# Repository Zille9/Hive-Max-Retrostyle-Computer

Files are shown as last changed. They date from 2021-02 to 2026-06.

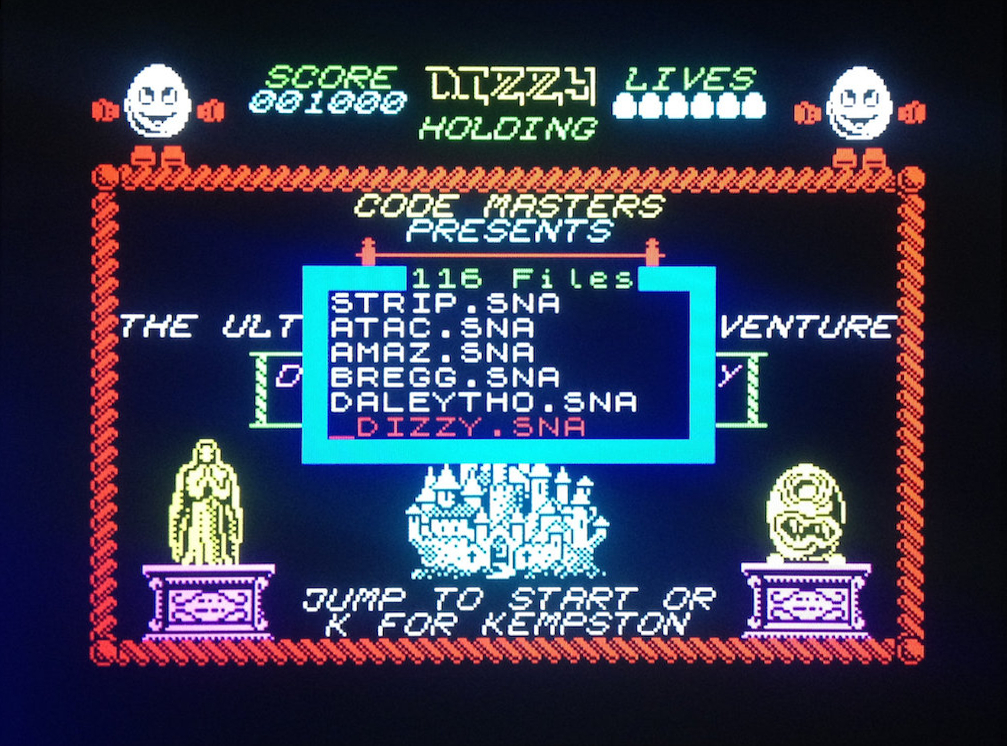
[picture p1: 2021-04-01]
Pictures/spectrum.JPG

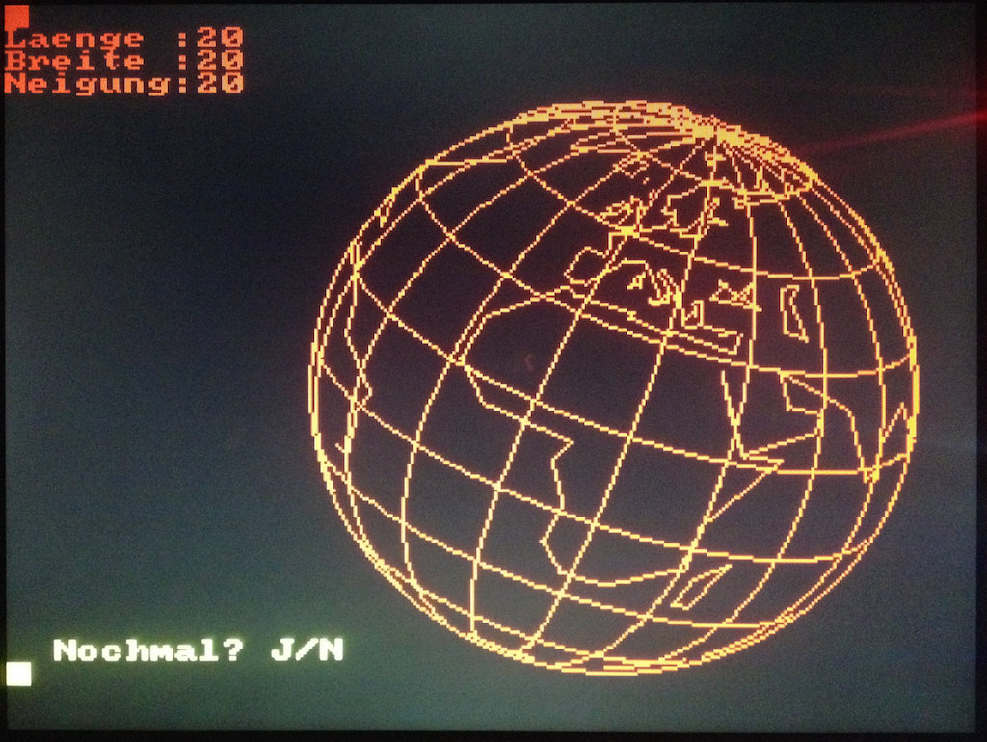
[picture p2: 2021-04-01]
Pictures/IMG_1200.JPG

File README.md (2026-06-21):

# Hive-Max-Retrostyle-Computer
umfangreich erweiterter Hive-Retrostyle-Computer

Folgende Änderungen wurden durchgeführt:
- 2xJoystick Ports (wie Mini-Joystickkarte)
- Bellatrix-Ram-Erweiterung integriert (für Emulatoren)
- Umschaltung Soundquelle von Administra nach Bellatrix (für Emulatoren)
- zusätzlicher Latchbaustein für die Aktivierung/Deaktivierung zusätzlicher Funktionen
- Portsperren am Bellatrix VGA-Ausgang, um die Ports für eigene Erweiterungen zu nutzen (andere Grafikhardware, CP/M-Emulation usw.)
- Möglichkeit der Anbindung des Micromite an den Hive
- Expansionsport als C64 Modulport ausgebildet für Hardware-Steckmodule
- automatische EEPROM-Umschaltung durch die Steckmodule über Adressumschaltung
- Latch-Diagnoseanschluss für den Zusatzlatch zur Funktionskontrolle

Für weitere Informationen siehe auch https://hive-project.de

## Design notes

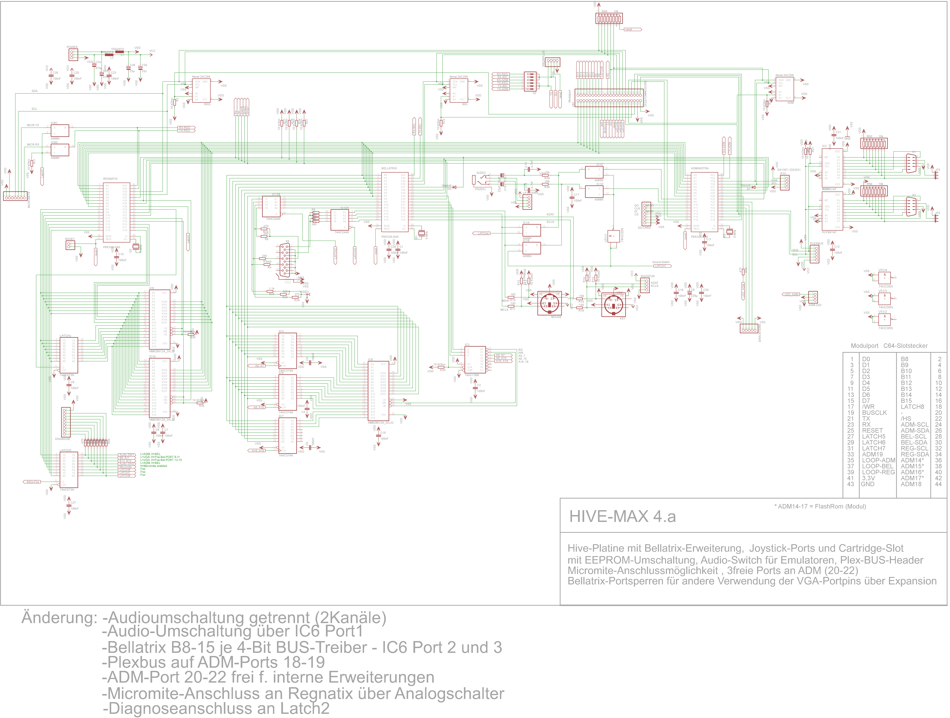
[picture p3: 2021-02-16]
Hive_Max_4a-Schematic.png

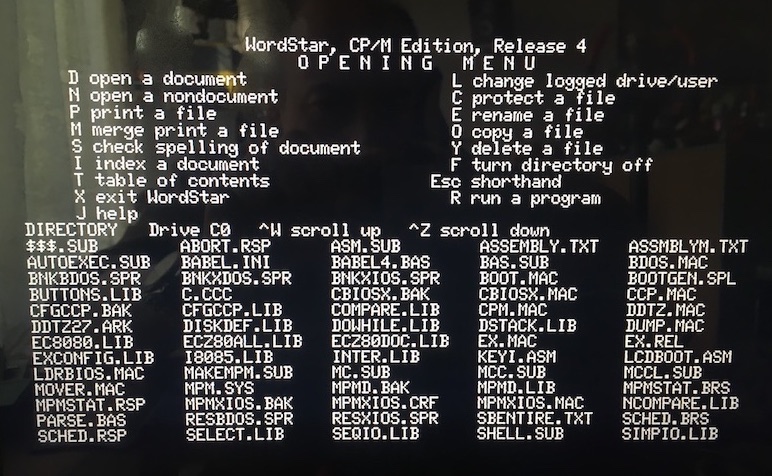
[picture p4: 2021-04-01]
Pictures/CPM-Hive.JPG

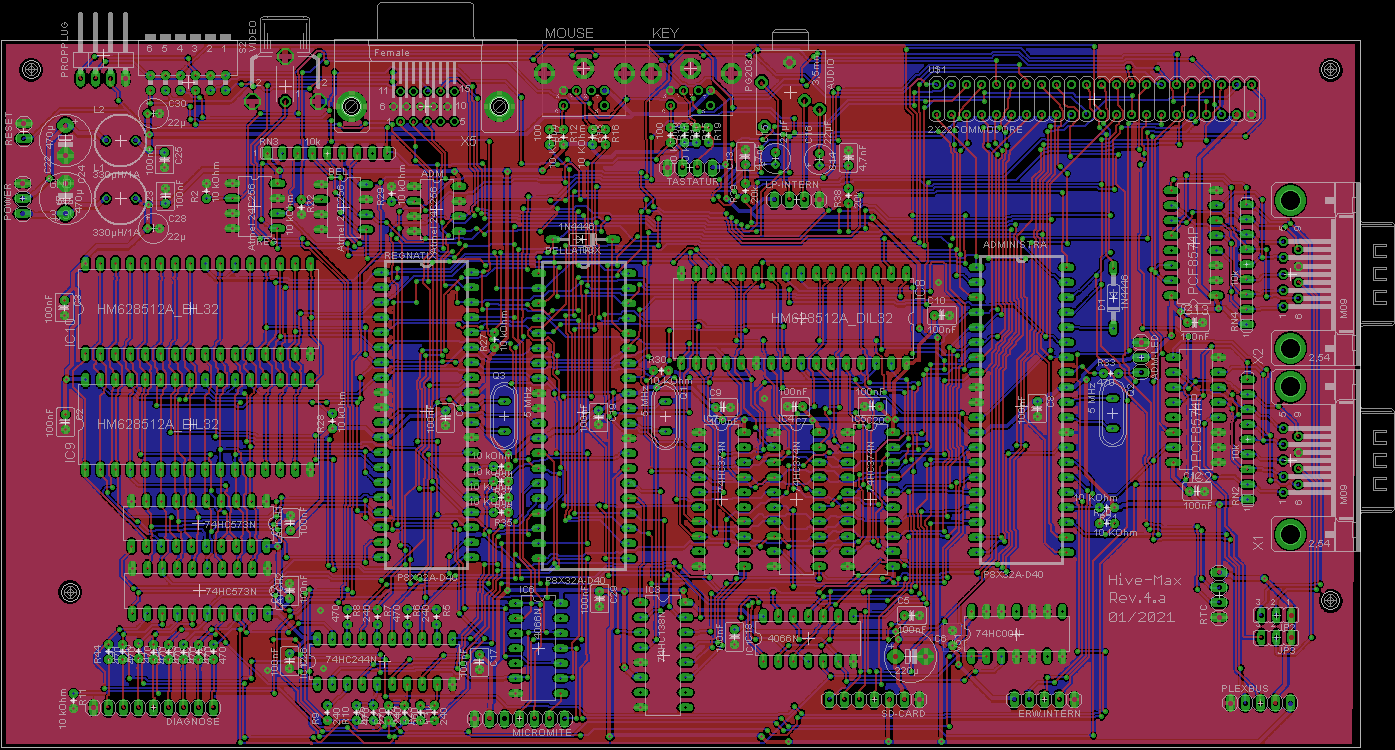
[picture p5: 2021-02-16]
Hive_Max_4a-Board.png

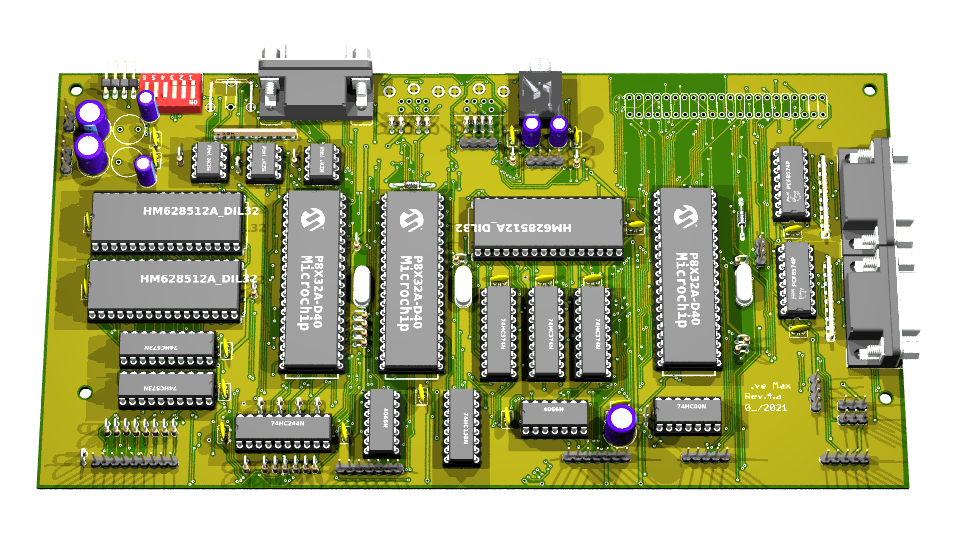
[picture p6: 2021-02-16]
3D-Ansicht.png

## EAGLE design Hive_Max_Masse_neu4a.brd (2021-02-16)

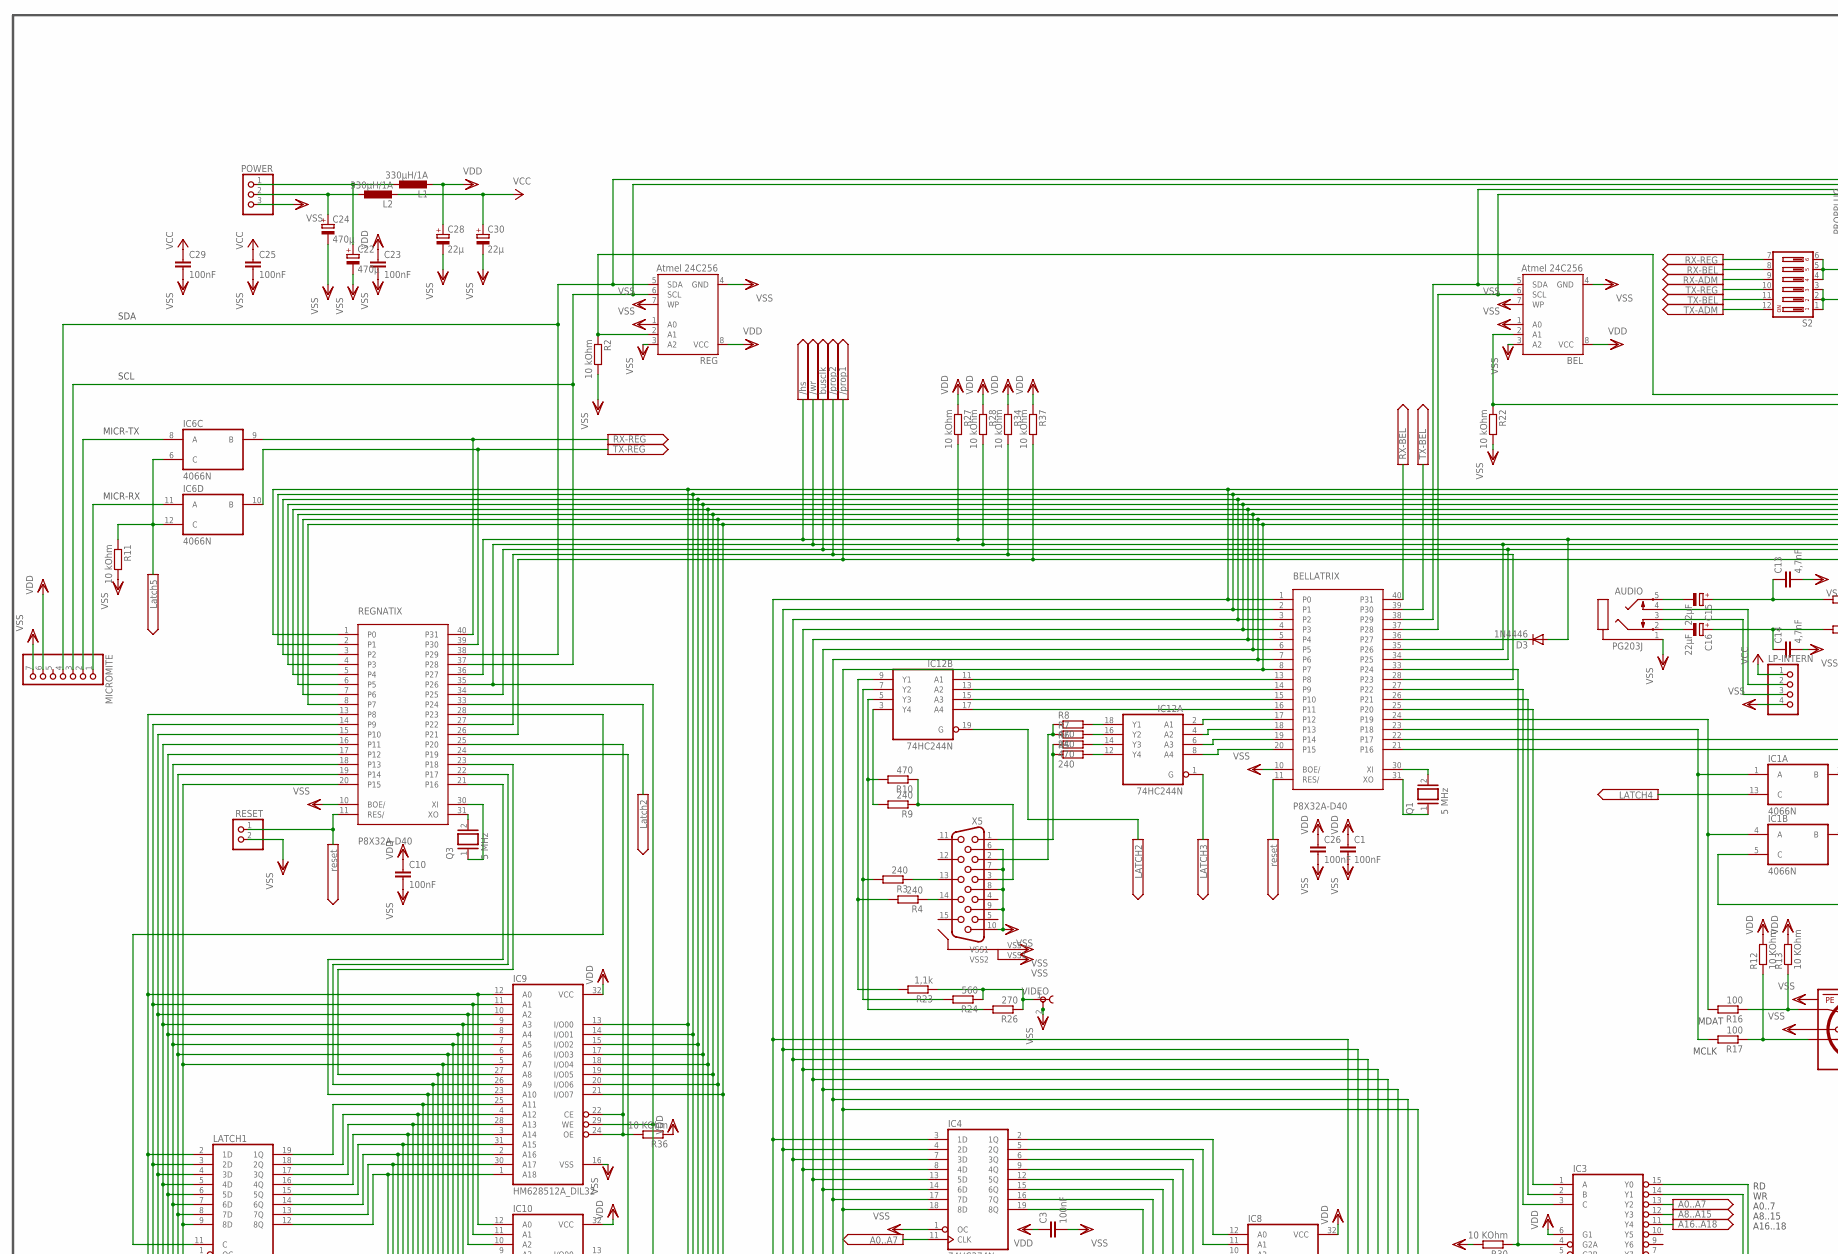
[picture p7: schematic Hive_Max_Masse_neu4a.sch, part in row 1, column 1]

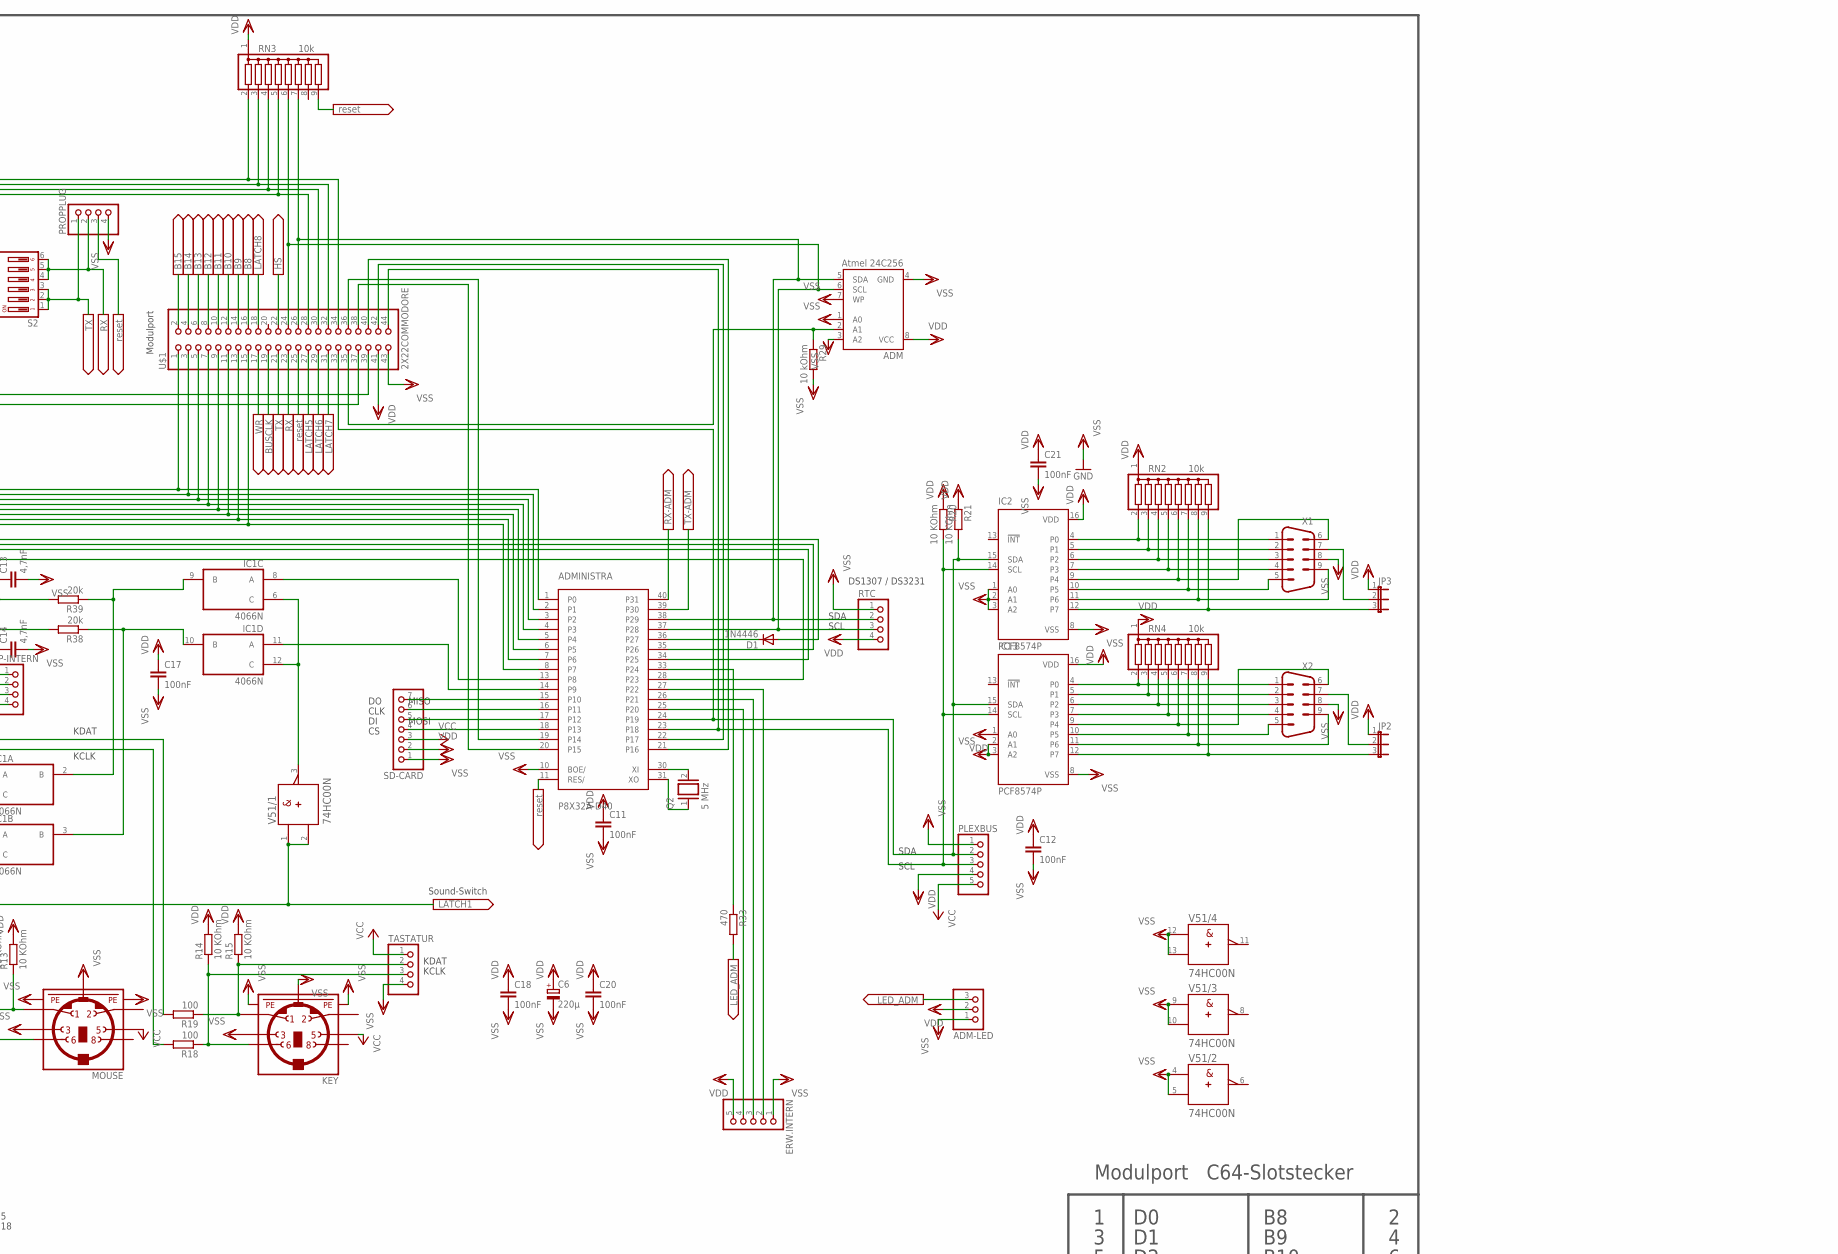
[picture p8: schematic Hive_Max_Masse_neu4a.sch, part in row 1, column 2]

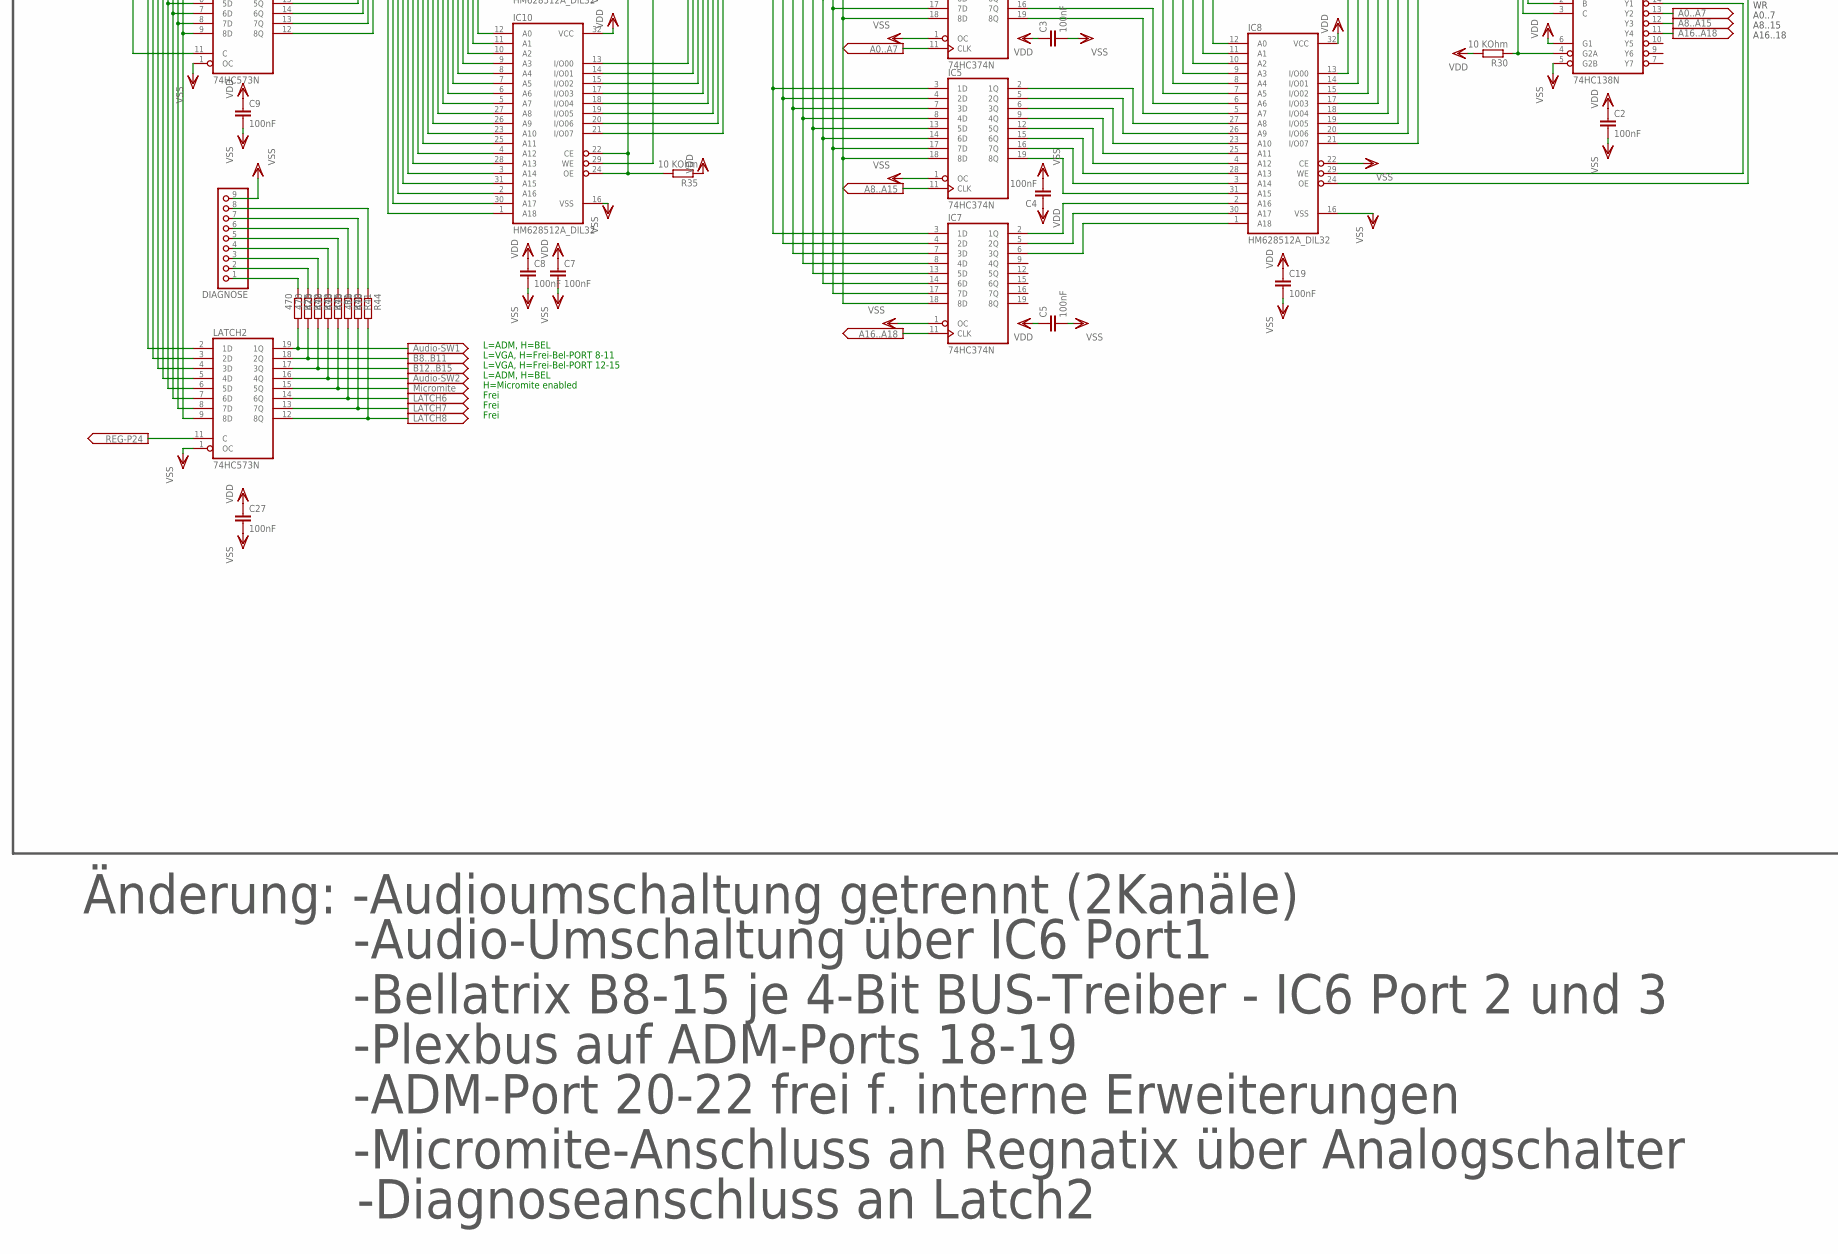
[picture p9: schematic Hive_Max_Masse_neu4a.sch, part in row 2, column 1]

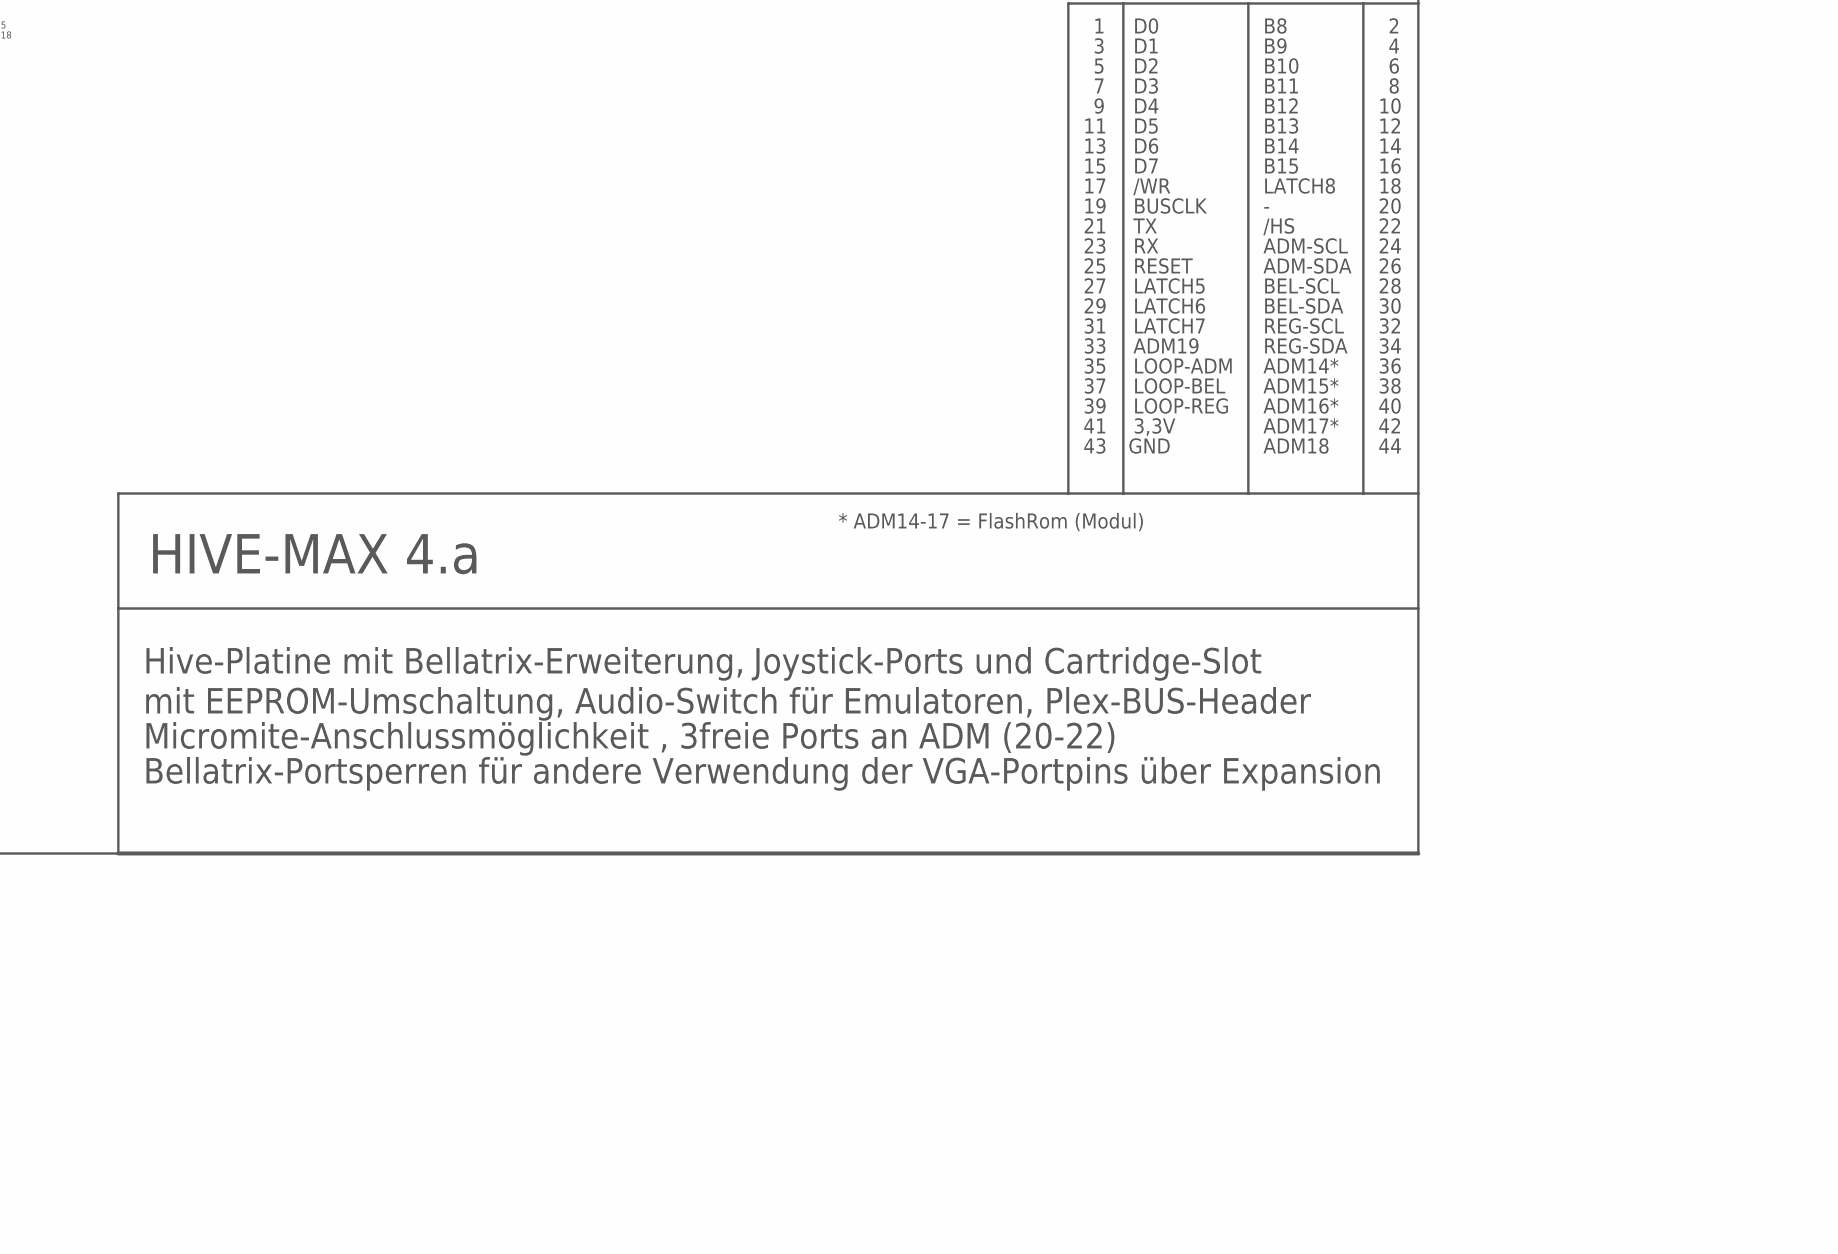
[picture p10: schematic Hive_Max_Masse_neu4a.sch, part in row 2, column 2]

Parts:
ADM: Atmel 24C256; DIL08
ADM-LED: PINHD-1X3; 1X03
ADMINISTRA: P8X32A-D40
AUDIO: PG203J
BEL: Atmel 24C256; DIL08
BELLATRIX: P8X32A-D40
C1, C2, C3, C4, C5, C7, C8, C9, C10, C11, C12, C17, C18, C19, C20, C21, C23, C25, C26, C27, C29: 100nF; C025-030X050
C6: 220µ; E5-8,5
C13, C14: 4,7nF; C025-030X050
C15, C16: 22µF; E2-5
C22, C24: 470µ; E5-8,5
C28, C30: 22µ; E2-5
D1, D3: 1N4446; DO35-10
DIAGNOSE: PINHD-1X9; 1X09
ERW.INTERN: PINHD-1X5; 1X05
IC1, IC6: 4066N; DIL14
IC2, IC13: PCF8574P; DIL16
IC3: 74HC138N; DIL16
IC4, IC5, IC7: 74HC374N; DIL20
IC8, IC9, IC10: HM628512A_DIL32; DIL32
IC12: 74HC244N; DIL20
JP2, JP3: JP2E; JP2
KEY: MINI_DIN_6; M_DIN6
L1, L2: 330µH/1A; 6000-XXXX-RC
LATCH1, LATCH2: 74HC573N; DIL20
LP-INTERN: PINHD-1X4; 1X04
MICROMITE: PINHD-1X7; 1X07
MOUSE: MINI_DIN_6; M_DIN6
PLEXBUS: PINHD-1X5; 1X05
POWER: PINHD-1X3; 1X03
PROPPLUG: PINHD-1X4/90; 1X04/90
Q1, Q2, Q3: 5 MHz; QS
R1, R6, R8, R10, R25, R33, R40, R41, R42, R43, R44, R45: 470; 0204V
R2, R11, R22, R27, R28, R29, R34, R37: 10 kOhm; 0204V
R3, R4, R5, R7, R9: 240; 0204V
R12, R13, R14, R15, R20, R21, R30, R35, R36: 10 KOhm; 0204V
R16, R17, R18, R19: 100; 0204V
R23: 1,1k; 0204V
R24: 560; 0204V
R26: 270; 0204V
R38, R39: 20k; 0204V
REG: Atmel 24C256; DIL08
REGNATIX: P8X32A-D40
RESET: PINHD-1X2; 1X02
RN2, RN3, RN4: 10k; SIL9
RTC: PINHD-1X4; 1X04
S2: DA06; DA-06
SD-CARD: PINHD-1X7; 1X07
TASTATUR: PINHD-1X4; 1X04
U$1: 2X22COMMODORE; 2X22-COMMODORE
V51: 74HC00N; DIL14
VIDEO: CINCHFEM; TOBU3
X1, X2: M09HP
X5: HF15H; HDF15H

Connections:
/HS: D1.A, D3.A, R27.2, REGNATIX.36 (P27), U$1.22
A0: IC9.12 (A0), IC10.12 (A0), LATCH1.2 (1D), LATCH2.2 (1D), REGNATIX.13 (P8)
A0..A7: IC3.13 (Y2), IC4.11 (CLK)
A1: IC9.11 (A1), IC10.11 (A1), LATCH1.3 (2D), LATCH2.3 (2D), REGNATIX.14 (P9)
A2: IC9.10 (A2), IC10.10 (A2), LATCH1.4 (3D), LATCH2.4 (3D), REGNATIX.15 (P10)
A3: IC9.9 (A3), IC10.9 (A3), LATCH1.5 (4D), LATCH2.5 (4D), REGNATIX.16 (P11)
A4: IC9.8 (A4), IC10.8 (A4), LATCH1.6 (5D), LATCH2.6 (5D), REGNATIX.17 (P12)
A5: IC9.7 (A5), IC10.7 (A5), LATCH1.7 (6D), LATCH2.7 (6D), REGNATIX.18 (P13)
A6: IC9.6 (A6), IC10.6 (A6), LATCH1.8 (7D), LATCH2.8 (7D), REGNATIX.19 (P14)
A7: IC9.5 (A7), IC10.5 (A7), LATCH1.9 (8D), LATCH2.9 (8D), REGNATIX.20 (P15)
A8: IC9.23 (A10), IC10.23 (A10), REGNATIX.21 (P16)
A8..A15: IC3.12 (Y3), IC5.11 (CLK)
A9: IC9.26 (A9), IC10.26 (A9), REGNATIX.22 (P17)
A10: IC9.27 (A8), IC10.27 (A8), REGNATIX.23 (P18)
A16..A18: IC3.11 (Y4), IC7.11 (CLK)
ADM14: ADMINISTRA.19 (P14), U$1.36
ADM15: ADMINISTRA.20 (P15), U$1.38
ADM16: ADMINISTRA.21 (P16), U$1.40
ADM17: ADMINISTRA.22 (P17), U$1.42
ADM18: ADMINISTRA.23 (P18), IC2.14 (SCL), IC13.14 (SCL), PLEXBUS.3, R20.2, U$1.44
ADM19: ADMINISTRA.24 (P19), IC2.15 (SDA), IC13.15 (SDA), PLEXBUS.2, R21.2, U$1.33
ADM20: ADMINISTRA.25 (P20), ERW.INTERN.4
ADM21: ADMINISTRA.26 (P21), ERW.INTERN.3
ADM22: ADMINISTRA.27 (P22), ERW.INTERN.2
ADM-SCL: ADM.6 (SCL), ADMINISTRA.37 (P28), RN3.6, RTC.3, U$1.24
ADM-SDA: ADM.5 (SDA), ADMINISTRA.38 (P29), RN3.7, RTC.2, U$1.26
B8: BELLATRIX.13 (P8), IC12.11 (A1), U$1.16
B9: BELLATRIX.14 (P9), IC12.13 (A2), U$1.14
B10: BELLATRIX.15 (P10), IC12.15 (A3), U$1.12
B11: BELLATRIX.16 (P11), IC12.17 (A4), U$1.10
B12: BELLATRIX.17 (P12), IC12.2 (A1), U$1.8
B13: BELLATRIX.18 (P13), IC12.4 (A2), U$1.6
B14: BELLATRIX.19 (P14), IC12.6 (A3), U$1.4
B15: BELLATRIX.20 (P15), IC12.8 (A4), U$1.2
BEL-SCL: BEL.6 (SCL), BELLATRIX.37 (P28), RN3.5, U$1.28
BEL-SDA: BEL.5 (SDA), BELLATRIX.38 (P29), RN3.4, U$1.30
BLAU: R9.1, R10.1, X5.3
BUSCLK: ADMINISTRA.34 (P25), BELLATRIX.34 (P25), REGNATIX.34 (P25), U$1.19
CLK: KEY.6, R14.1, R18.1, TASTATUR.3
D0: ADMINISTRA.1 (P0), BELLATRIX.1 (P0), IC4.3 (1D), IC5.3 (1D), IC7.3 (1D), IC8.13 (I/O00), IC9.13 (I/O00), IC10.13 (I/O00), REGNATIX.1 (P0), U$1.1
D1: ADMINISTRA.2 (P1), BELLATRIX.2 (P1), IC4.4 (2D), IC5.4 (2D), IC7.4 (2D), IC8.14 (I/O01), IC9.14 (I/O01), IC10.14 (I/O01), REGNATIX.2 (P1), U$1.3
D2: ADMINISTRA.3 (P2), BELLATRIX.3 (P2), IC4.7 (3D), IC5.7 (3D), IC7.7 (3D), IC8.15 (I/O02), IC9.15 (I/O02), IC10.15 (I/O02), REGNATIX.3 (P2), U$1.5
D3: ADMINISTRA.4 (P3), BELLATRIX.4 (P3), IC4.8 (4D), IC5.8 (4D), IC7.8 (4D), IC8.17 (I/O03), IC9.17 (I/O03), IC10.17 (I/O03), REGNATIX.4 (P3), U$1.7
D4: ADMINISTRA.5 (P4), BELLATRIX.5 (P4), IC4.13 (5D), IC5.13 (5D), IC7.13 (5D), IC8.18 (I/O04), IC9.18 (I/O04), IC10.18 (I/O04), REGNATIX.5 (P4), U$1.9
D5: ADMINISTRA.6 (P5), BELLATRIX.6 (P5), IC4.14 (6D), IC5.14 (6D), IC7.14 (6D), IC8.19 (I/O05), IC9.19 (I/O05), IC10.19 (I/O05), REGNATIX.6 (P5), U$1.11
D6: ADMINISTRA.7 (P6), BELLATRIX.7 (P6), IC4.17 (7D), IC5.17 (7D), IC7.17 (7D), IC8.20 (I/O06), IC9.20 (I/O06), IC10.20 (I/O06), REGNATIX.7 (P6), U$1.13
D7: ADMINISTRA.8 (P7), BELLATRIX.8 (P7), IC4.18 (8D), IC5.18 (8D), IC7.18 (8D), IC8.21 (I/O07), IC9.21 (I/O07), IC10.21 (I/O07), REGNATIX.8 (P7), U$1.15
DAT: KEY.1, R15.1, R19.1, TASTATUR.2
GLOB_RESET: ADMINISTRA.11 (RES/), BELLATRIX.11 (RES/), PROPPLUG.3, REGNATIX.11 (RES/), RESET.1, RN3.9, U$1.25
GRUEN: R7.1, R8.1, X5.2
HSYNC: R3.1, X5.13
KCLK: BELLATRIX.21 (P16), R18.2
KDAT: BELLATRIX.22 (P17), R19.2
LATCH1: IC1.5 (C), LATCH2.19 (1Q), R25.2, V51.1 (A), V51.2 (B)
LATCH2: IC12.19 (G), LATCH2.18 (2Q), R42.2
LATCH3: IC12.1 (G), LATCH2.17 (3Q), R43.2
LATCH4: IC1.13 (C), LATCH2.16 (4Q), R45.2
LATCH5: IC6.6 (C), IC6.12 (C), LATCH2.15 (5Q), R1.2, R11.1, U$1.27
LATCH6: LATCH2.14 (6Q), R40.2, U$1.29
LATCH7: LATCH2.13 (7Q), R41.2, U$1.31
LATCH8: LATCH2.12 (8Q), R44.2, U$1.18
LED_ADM: ADM-LED.3, R33.2
LOOP-ADM: ADM.2 (A1), R29.1, U$1.35
LOOP-BEL: BEL.2 (A1), R22.1, U$1.37
LOOP-REG: R2.1, REG.2 (A1), U$1.39
MCLK: BELLATRIX.23 (P18), IC1.1 (A), R17.2
MDAT: BELLATRIX.24 (P19), IC1.4 (A), R16.2
unnamed: AUDIO.4, LP-INTERN.2
unnamed: AUDIO.3, LP-INTERN.3
unnamed: ADMINISTRA.14 (P9), IC1.11 (A)
unnamed: DIAGNOSE.1, R25.1
unnamed: IC12.18 (Y1), R8.2
unnamed: IC6.11 (A), MICROMITE.1
unnamed: DIAGNOSE.2, R42.1
unnamed: IC12.16 (Y2), R7.2
unnamed: IC12.14 (Y3), R6.2
unnamed: C22.+, L1.1, POWER.1
unnamed: C24.+, L2.1, POWER.2
unnamed: IC12.12 (Y4), R5.2
unnamed: IC6.8 (A), MICROMITE.2
unnamed: IC12.9 (Y1), R4.2, R23.2
unnamed: IC12.7 (Y2), R3.2, R24.2
unnamed: ADMINISTRA.30 (XI), Q2.2
unnamed: IC4.2 (1Q), IC8.12 (A0)
unnamed: IC4.5 (2Q), IC8.11 (A1)
unnamed: IC4.6 (3Q), IC8.10 (A2)
unnamed: IC4.9 (4Q), IC8.9 (A3)
unnamed: IC4.12 (5Q), IC8.8 (A4)
unnamed: IC12.5 (Y3), R10.2, R26.2
unnamed: DIAGNOSE.3, R43.1
unnamed: DIAGNOSE.4, R45.1
unnamed: DIAGNOSE.5, R1.1
unnamed: IC1.3 (B), IC1.10 (B), R38.1
unnamed: IC1.6 (C), IC1.12 (C), V51.3 (Y)
unnamed: IC12.3 (Y4), R9.2
unnamed: DIAGNOSE.6, R40.1
unnamed: DIAGNOSE.7, R41.1
unnamed: DIAGNOSE.8, R44.1
unnamed: BELLATRIX.30 (XI), Q1.2
unnamed: BELLATRIX.31 (XO), Q1.1
unnamed: BELLATRIX.36 (P27), D3.C
unnamed: IC1.2 (B), IC1.9 (B), R39.1
unnamed: MOUSE.1, R13.1, R16.1
unnamed: MOUSE.6, R12.1, R17.1
unnamed: ADMINISTRA.33 (P24), R33.1
unnamed: IC4.15 (6Q), IC8.7 (A5)
unnamed: IC4.16 (7Q), IC8.6 (A6)
unnamed: IC4.19 (8Q), IC8.5 (A7)
unnamed: R23.1, R24.1, R26.1, VIDEO.1
unnamed: ADMINISTRA.31 (XO), Q2.1
unnamed: IC5.2 (1Q), IC8.27 (A8)
unnamed: ADMINISTRA.15 (P10), SD-CARD.7
unnamed: ADMINISTRA.16 (P11), SD-CARD.6
unnamed: ADMINISTRA.17 (P12), SD-CARD.5
unnamed: ADMINISTRA.36 (P27), D1.C
unnamed: ADMINISTRA.18 (P13), SD-CARD.4
unnamed: Q3.2, REGNATIX.31 (XO)
unnamed: Q3.1, REGNATIX.30 (XI)
unnamed: IC2.7 (P3), RN2.5, X1.4
unnamed: IC2.4 (P0), RN2.2, X1.1
unnamed: IC5.5 (2Q), IC8.26 (A9)
unnamed: IC5.6 (3Q), IC8.23 (A10)
unnamed: IC5.9 (4Q), IC8.25 (A11)
unnamed: IC5.12 (5Q), IC8.4 (A12)
unnamed: IC5.15 (6Q), IC8.28 (A13)
unnamed: IC5.16 (7Q), IC8.3 (A14)
unnamed: IC5.19 (8Q), IC8.31 (A15)
unnamed: IC7.2 (1Q), IC8.2 (A16)
unnamed: IC7.5 (2Q), IC8.30 (A17)
unnamed: IC7.6 (3Q), IC8.1 (A18)
unnamed: IC9.25 (A11), IC10.25 (A11), LATCH1.19 (1Q)
unnamed: IC9.4 (A12), IC10.4 (A12), LATCH1.18 (2Q)
unnamed: IC9.28 (A13), IC10.28 (A13), LATCH1.17 (3Q)
unnamed: IC9.3 (A14), IC10.3 (A14), LATCH1.16 (4Q)
unnamed: IC9.31 (A15), IC10.31 (A15), LATCH1.15 (5Q)
unnamed: IC9.2 (A16), IC10.2 (A16), LATCH1.14 (6Q)
unnamed: IC9.30 (A17), IC10.30 (A17), LATCH1.13 (7Q)
unnamed: IC9.1 (A18), IC10.1 (A18), LATCH1.12 (8Q)
unnamed: LATCH1.11 (C), REGNATIX.28 (P23)
unnamed: IC2.5 (P1), RN2.3, X1.2
unnamed: IC2.6 (P2), RN2.4, X1.3
unnamed: IC13.7 (P3), RN4.5, X2.4
unnamed: IC13.9 (P4), RN4.6, X2.6
unnamed: IC2.10 (P5), RN2.7, X1.5
unnamed: IC2.9 (P4), RN2.6, X1.6
unnamed: IC2.12 (P7), JP3.3, RN2.9
unnamed: IC13.4 (P0), RN4.2, X2.1
unnamed: IC13.5 (P1), RN4.3, X2.2
unnamed: IC13.6 (P2), RN4.4, X2.3
unnamed: IC13.11 (P6), RN4.8, X2.9
unnamed: IC2.11 (P6), RN2.8, X1.9
unnamed: IC13.10 (P5), RN4.7, X2.5
unnamed: JP2.2, X2.7
unnamed: IC13.12 (P7), JP2.3, RN4.9
unnamed: JP3.2, X1.7
unnamed: ADMINISTRA.13 (P8), IC1.8 (A)
unnamed: AUDIO.2, C16.-
unnamed: AUDIO.5, C15.-
unnamed: C13.1, C15.+, R39.2
unnamed: C14.1, C16.+, R38.2
PROP1: ADMINISTRA.28 (P23), R37.2, REGNATIX.26 (P21)
PROP2: BELLATRIX.28 (P23), R34.2, REGNATIX.27 (P22)
RAM1: IC10.22 (CE), IC10.24 (OE), R35.2, REGNATIX.24 (P19)
RAM2: IC9.22 (CE), IC9.24 (OE), R36.2, REGNATIX.25 (P20)
RAM-RD: IC3.15 (Y0), IC8.24 (OE)
RAM-WR: IC3.14 (Y1), IC8.29 (WE)
REG-P24: LATCH2.11 (C), REGNATIX.33 (P24)
REG-SCL: MICROMITE.3, REG.6 (SCL), REGNATIX.37 (P28), RN3.3, U$1.32
REG-SDA: MICROMITE.4, REG.5 (SDA), REGNATIX.38 (P29), RN3.2, U$1.34
ROT: R5.1, R6.1, X5.1
RX: PROPPLUG.2, S2.4, S2.5, S2.6, U$1.23
RX-ADM: ADMINISTRA.40 (P31), S2.9
RX-BEL: BELLATRIX.40 (P31), S2.8
RX-REG: IC6.9 (B), REGNATIX.40 (P31), S2.7
TX: PROPPLUG.1, S2.1, S2.2, S2.3, U$1.21
TX-ADM: ADMINISTRA.39 (P30), S2.12
TX-BEL: BELLATRIX.39 (P30), S2.11
TX-REG: IC6.10 (B), REGNATIX.39 (P30), S2.10
VCC: C25.1, C29.1, C30.+, KEY.5, L2.2, LP-INTERN.1, MOUSE.5, PLEXBUS.5, SD-CARD.3, TASTATUR.1
VDD: ADM.8 (VCC), ADM-LED.2, ADMINISTRA.12 (VDD), ADMINISTRA.32 (VDD), BEL.8 (VCC), BELLATRIX.12 (VDD), BELLATRIX.32 (VDD), C1.1, C2.1, C3.1, C4.1, C5.1, C6.+, C7.1, C8.1, C9.1, C10.1, C11.1, C12.1, C17.1, C18.1, C19.1, C20.1, C21.1, C23.1, C26.1, C27.1, C28.+, ERW.INTERN.5, IC1.14 (VDD), IC2.16 (VDD), IC3.6 (G1), IC3.16 (VDD), IC4.20 (VDD), IC5.20 (VDD), IC6.14 (VDD), IC7.20 (VDD), IC8.32 (VCC), IC9.32 (VCC), IC10.32 (VCC), IC12.20 (VDD), IC13.1 (A0), IC13.16 (VDD), JP2.1, JP3.1, L1.2, LATCH1.20 (VDD), LATCH2.20 (VDD), MICROMITE.6, PLEXBUS.4, R12.2, R13.2, R14.2, R15.2, R20.1, R21.1, R27.1, R28.1, R30.2, R34.1, R35.1, R36.1, R37.1, REG.8 (VCC), REGNATIX.12 (VDD), REGNATIX.32 (VDD), RN2.1, RN3.1, RN4.1, RTC.4, SD-CARD.2, U$1.41, V51.14 (VDD)
VSS: ADM.1 (A0), ADM.3 (A2), ADM.4 (GND), ADM.7 (WP), ADM-LED.1, ADMINISTRA.9 (GND), ADMINISTRA.10 (BOE/), ADMINISTRA.29 (GND), AUDIO.1, BEL.1 (A0), BEL.3 (A2), BEL.4 (GND), BEL.7 (WP), BELLATRIX.9 (GND), BELLATRIX.10 (BOE/), BELLATRIX.29 (GND), C1.2, C2.2, C3.2, C4.2, C5.2, C6.-, C7.2, C8.2, C9.2, C10.2, C11.2, C12.2, C13.2, C14.2, C17.2, C18.2, C19.2, C20.2, C21.2, C22.-, C23.2, C24.-, C25.2, C26.2, C27.2, C28.-, C29.2, C30.-, DIAGNOSE.9, ERW.INTERN.1, IC1.7 (VSS), IC2.1 (A0), IC2.2 (A1), IC2.3 (A2), IC2.8 (VSS), IC3.5 (G2B), IC3.8 (GND), IC4.1 (OC), IC4.10 (GND), IC5.1 (OC), IC5.10 (GND), IC6.7 (VSS), IC7.1 (OC), IC7.10 (GND), IC8.16 (VSS), IC8.22 (CE), IC9.16 (VSS), IC10.16 (VSS), IC12.10 (GND), IC13.2 (A1), IC13.3 (A2), IC13.8 (VSS), KEY.3, KEY.SH1 (PE1), KEY.SH2 (PE2), KEY.SH3 (PE3), LATCH1.1 (OC), LATCH1.10 (GND), LATCH2.1 (OC), LATCH2.10 (GND), LP-INTERN.4, MICROMITE.7, MOUSE.3, MOUSE.SH1 (PE1), MOUSE.SH2 (PE2), MOUSE.SH3 (PE3), PLEXBUS.1, POWER.3, PROPPLUG.4, R2.2, R11.2, R22.2, R29.2, REG.1 (A0), REG.3 (A2), REG.4 (GND), REG.7 (WP), REGNATIX.9 (GND), REGNATIX.10 (BOE/), REGNATIX.29 (GND), RESET.2, RTC.1, SD-CARD.1, TASTATUR.4, U$1.43, V51.4 (A), V51.5 (B), V51.7 (VSS), V51.9 (A), V51.10 (B), V51.12 (A), V51.13 (B), VIDEO.2, VIDEO.2@1 (3), VIDEO.2@2 (4), X1.8, X2.8, X5.6, X5.7, X5.8, X5.9, X5.10, X5.VSS (VSS1), X5.VSS1 (VSS2)
VSYNC: R4.1, X5.14
WR: ADMINISTRA.35 (P26), BELLATRIX.35 (P26), IC9.29 (WE), IC10.29 (WE), R28.2, REGNATIX.35 (P26), U$1.17
Y1: BELLATRIX.25 (P20), IC3.1 (A)
Y2: BELLATRIX.26 (P21), IC3.2 (B)
Y3: BELLATRIX.27 (P22), IC3.3 (C)
Y4: BELLATRIX.33 (P24), IC3.4 (G2A), R30.1

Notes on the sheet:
B10
B13
LATCH8
GND
3,3V
B11
B12
B14
B15
/HS
REG-SCL
BEL-SDA
BEL-SCL
ADM-SDA
ADM-SCL
/WR
BUSCLK
REG-SDA
ADM14*
ADM15*
ADM16*
ADM17*
ADM18
RESET
MCLK
MDAT
KDAT
KCLK
A0..7
A8..15
A16..18
CLK
Modulport
DS1307 / DS3231
HIVE-MAX 4.a
Hive-Platine mit Bellatrix-Erweiterung,
Joystick-Ports und Cartridge-Slot
mit EEPROM-Umschaltung, Audio-Switch für Emulatoren, Plex-BUS-Header
LATCH5
LATCH6

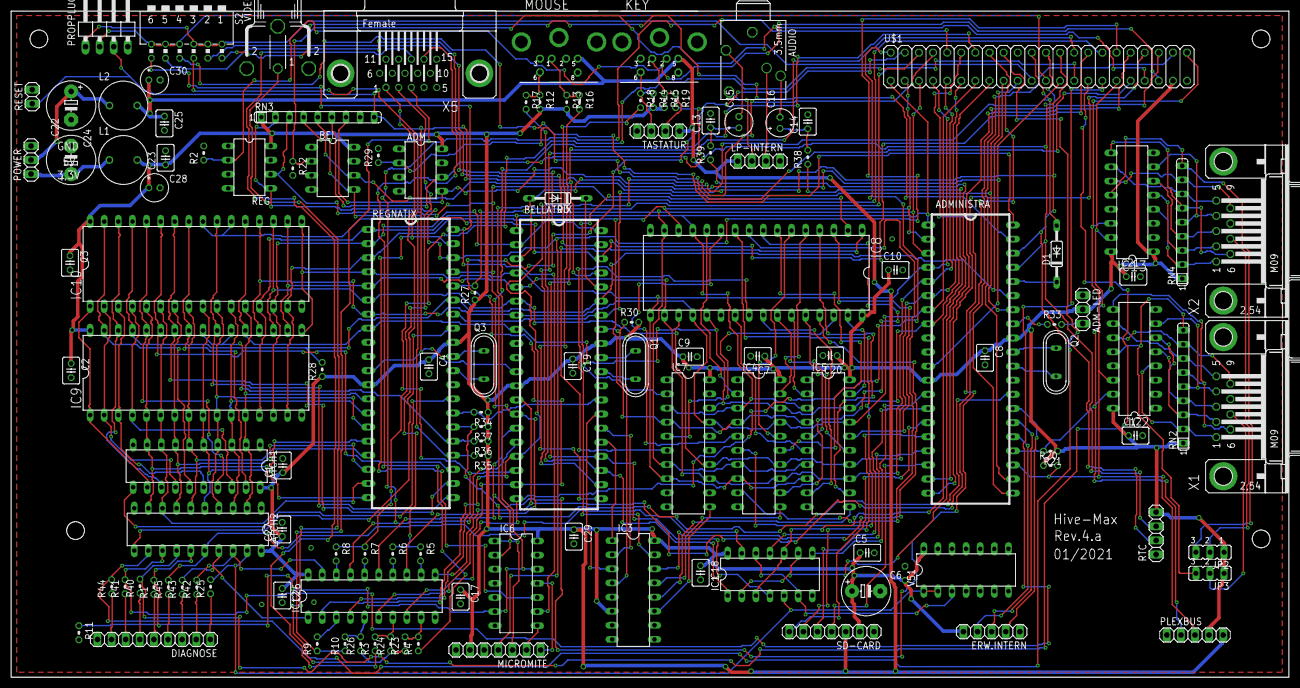
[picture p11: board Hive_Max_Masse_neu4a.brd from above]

Board: 2 copper layers, 230.0 x 119.9 mm, 127 parts (1 on the bottom side), 187 nets.
